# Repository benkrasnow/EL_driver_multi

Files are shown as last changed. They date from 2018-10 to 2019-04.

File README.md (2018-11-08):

# EL_driver_multi
Schematic, PCB, and firmware to build a multi-channel electroluminescent display driver

The MCU must be programmed with Adafruit's bootloader.  The programming pins are exposed on this PCB, but a potentially easier way is to buy a Trinket M0, and use a hotplate to remove the MCU, button, decoupling caps, LEDs current-limiting resistors and USB connector, and add those parts to this PCB.

The firmware for the driving of linear display elements (EL_array_linear) is pretty stable and well-commented.  The firmware for matrix driving (EL_array_matrix) is much more experimental.  It's accompanying Processing.org sketch is also a pretty hacked mod of Paul Stoffregen's original OctoWS2811 driver.

Driving EL matrix displays is not straightforward because scanning the matrix will undesirably illuminate pixels that are intended to be dark. This problem manifests as vertical bars in the image (when horizontal rows are scanned).  This could be improved with a tri-state high voltage shift register.

Video of my talk at Hackaday Supercon 2018, starting at the EL driver section:   https://youtu.be/Tx2B5hI4w1U?t=1473



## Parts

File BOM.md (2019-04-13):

Bill of Materials
---
|ID|Part Number|Description|Qty.|
|---|---|---|---|
|**HV Charge Circuit**|
|TR1, TR2|ATB3225|Step-Up Transformer|2|
|U2, U6|LT3468| Photoflash Charger|2|
|D1, D2|B0540W|0.5A SOD123 SCHOTTKY BARRIER RECTIFIER|2|
|D3, D4|MMBD5004S|HIGH VOLTAGE DUAL SWITCHING DIODE|2|
|C4|-|2.2μF 2220 (5750) SMD Capacitor|1|
|C5, C9|-|6.3μF 0603 SMD Capacitor|2|
|C6|-|100pF 0603 SMD Capacitor|1|
|R2|-|10MOhm 0603 SMD Resistor|1|
|R3|-|100kOhm 0603 SMD Resistor|1|
|**HV Control Circuit**|
|U1|HV513|8-Channel Low voltage serial to high voltage parallel IC|1|
| | |*OR*| |
|U9|HV507|64-Channel Low voltage serial to high voltage parallel IC|1|
|**LV Control Circuit**| |*All Components possibly from Tinket-M0*|
|U?|ATSAMD21E|Trinket M0 CPU|1|
|U3|AP2204K-3.3|3.3V Voltage regulator|1|
|U4|AP2204K-5.0|5.0V Voltage regulator|1|
|C2, C3|-|1μF 0603 SMD Capacitor|2|
|C1, C7, C8|-|10μF 0805 SMD Capacitor|3|
|R1|-|1.5kOhm 0603 SMD Resistor|1|
|R4|-|10kOhm 0603 SMD Resistor|1|
|L1|-|Red 0603 SMD LED|1|
|PWR1|-|Green Bright 0603 SMD LED|1|
|Q2|-|Tactile Switch SMT4.6X2.8|1|
|CN1|-|Micro USB Female|1|

Digikey Cart
---
*Parts excluding 0603 caps and resistors, and microcontroller stuff:*
- Double quantity except for HV507 https://www.digikey.com/short/pc8p74
- Single quantity https://www.digikey.com/short/pc8p89

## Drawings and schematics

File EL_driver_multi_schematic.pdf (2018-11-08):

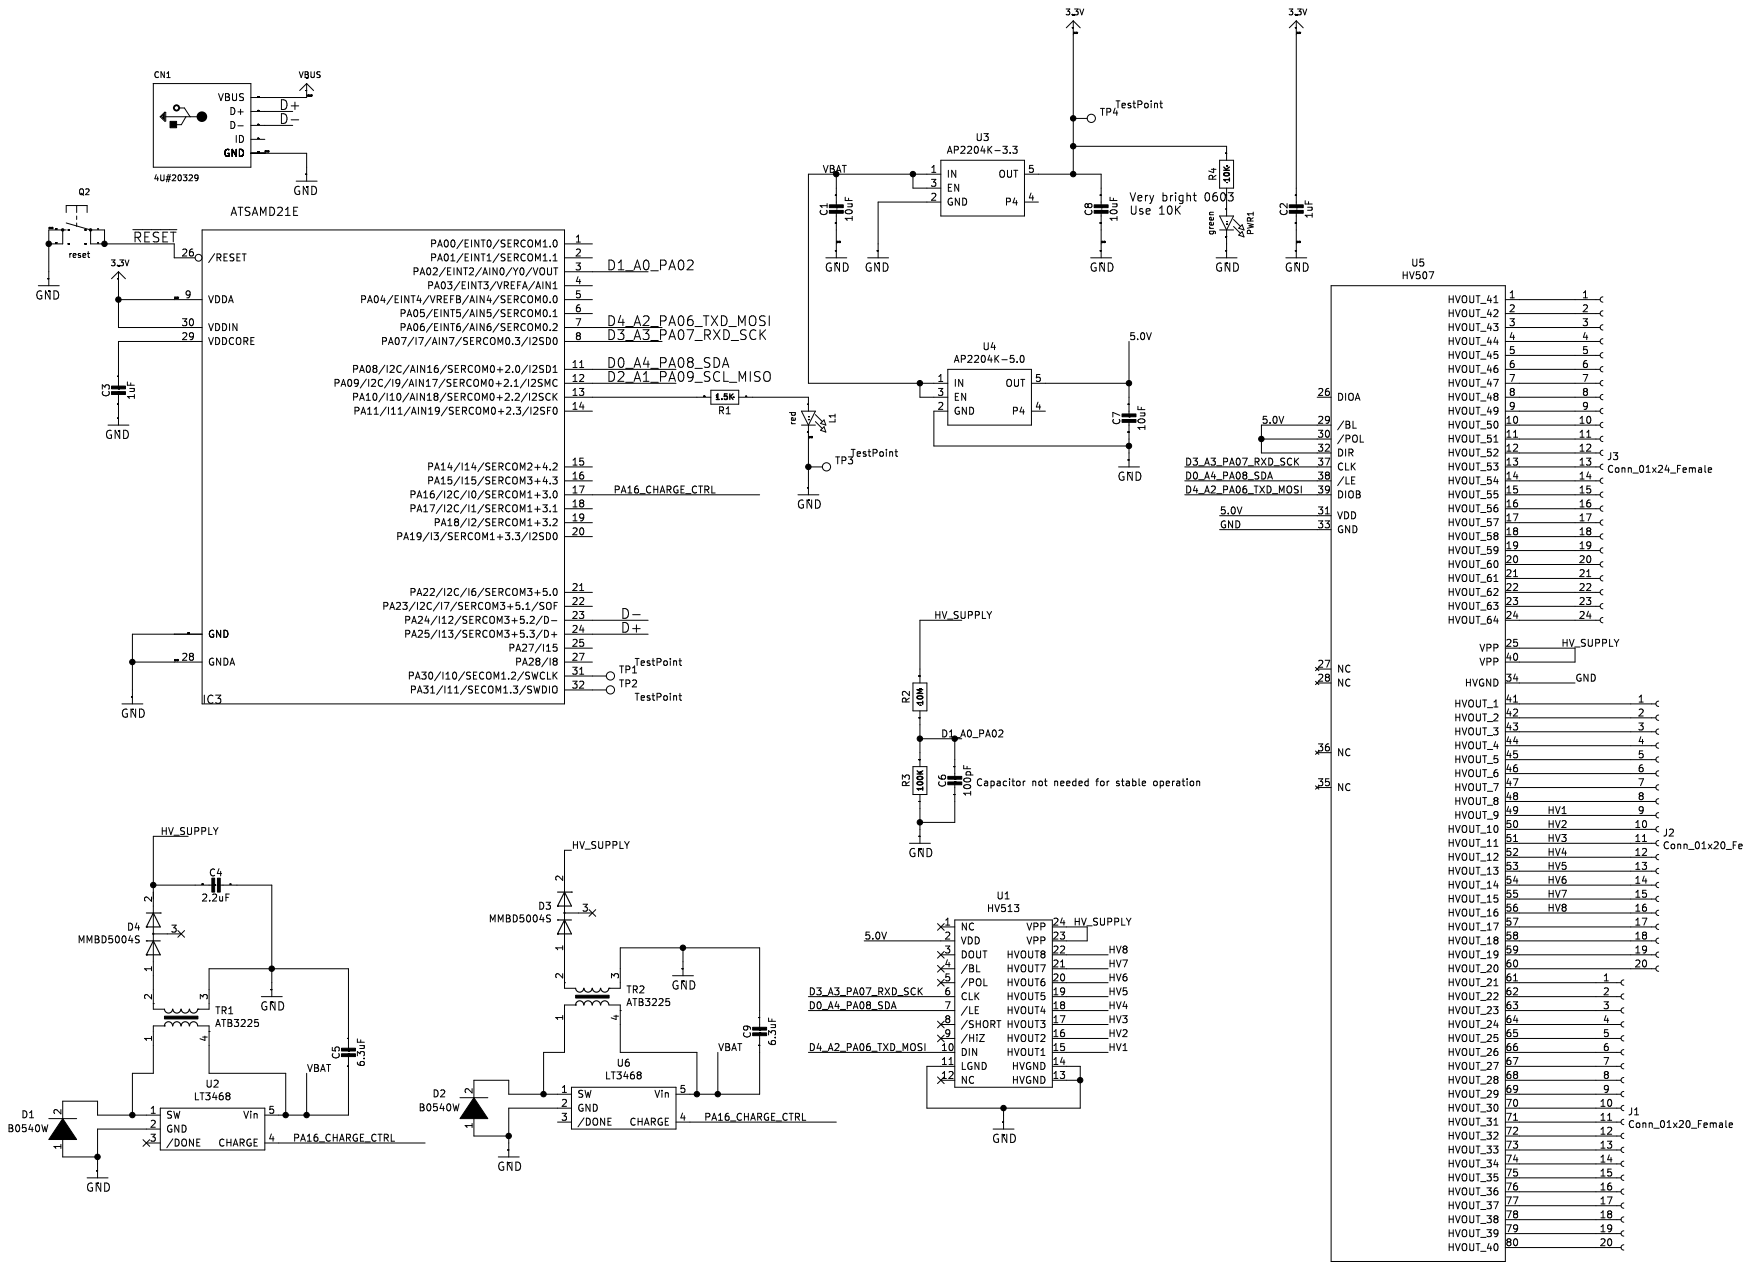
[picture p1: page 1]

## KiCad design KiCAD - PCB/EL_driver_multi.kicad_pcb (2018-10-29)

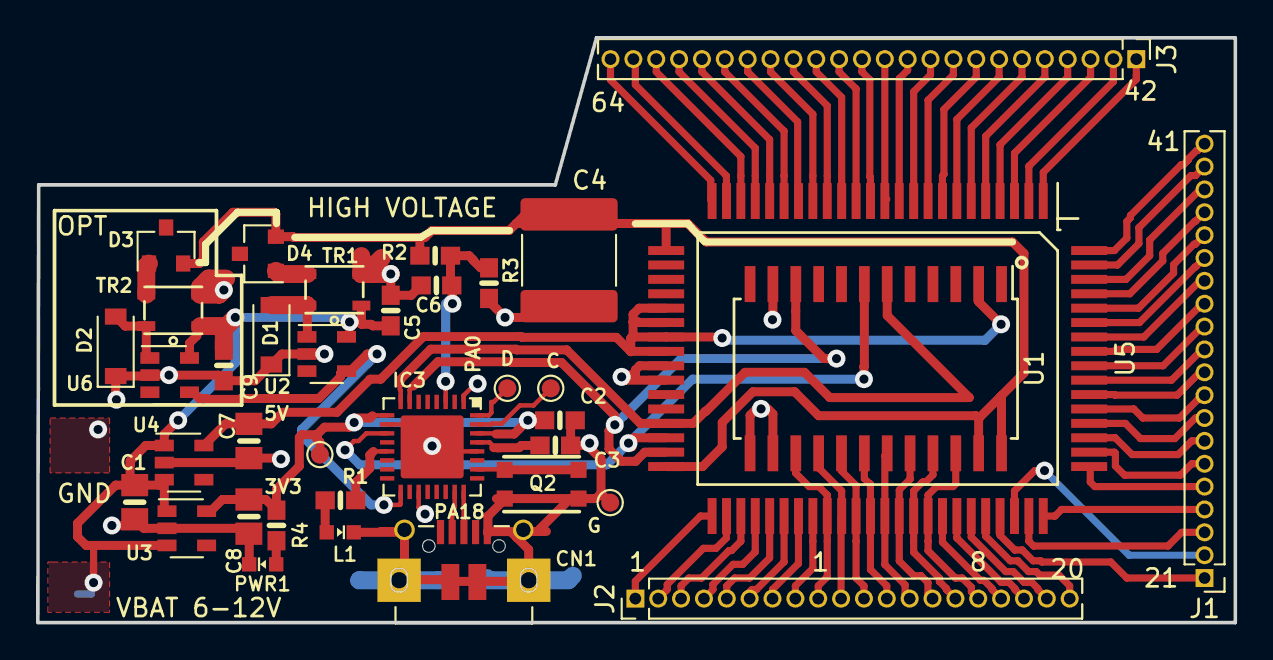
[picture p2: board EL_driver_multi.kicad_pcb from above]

Board: 2 copper layers, 66.5 x 32.5 mm, 37 parts (0 on the bottom side), 87 nets.

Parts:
C1, C7, C8: 10uF; 0805-NO
C2, C3: 1uF; 0603-NO
C4: 2.2uF; C_2220_5650Metric
C5, C9: 6.3uF; 0603-NO
C6: 0.1uF; 0603-NO
CN1: 4U#20329; 4UCONN_20329_V2
D1, D2: B0540W; D_SOD-123
D3, D4: MMBD5004S; SOT-23
IC3: ATSAMD21E; QFN32_5MM
J1, J2: Conn_01x20_Female; PinHeader_1x20_P1.27mm_Vertical
J3: Conn_01x24_Female; PinHeader_1x24_P1.27mm_Vertical
L1: red; CHIPLED_0603_NOOUTLINE
PWR1: green; CHIPLED_0603_NOOUTLINE
Q2: reset; BTN_KMR2_4.6X2.8
R1: 1.5K; 0603-NO
R2: 10M; 0603-NO
R3: 100K; 0603-NO
R4: 10K; 0603-NO
TP1, TP2, TP3, TP4: TestPoint; TestPoint_Pad_D1.0mm
TR1, TR2: ATB3225
U1: HV513; SOIC-24W_7.5x15.4mm_P1.27mm
U2, U6: LT3468; SOT-23-5
U3: AP2204K-3.3; SOT-23-5
U4: AP2204K-5.0; SOT-23-5
U5: HV507; QFP-96_14x20_Pitch0.8mm

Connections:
3.3V: C2.1, C8.1, IC3.9, IC3.30, R4.2, TP4.1, U3.5
/5.0V: C7.1, U1.2, U4.5, U5.29, U5.30, U5.31, U5.32
/D0_A4_PA08_SDA: IC3.11, U1.7, U5.38
/D1_A0_PA02: C6.1, IC3.3, R2.1, R3.2
/D3_A3_PA07_RXD_SCK: IC3.8, U1.6, U5.37
/D4_A2_PA06_TXD_MOSI: IC3.7, U1.10, U5.39
/D+: CN1.D+, IC3.24
/D-: CN1.D-, IC3.23
/HV1: J2.9, U1.15, U5.49
/HV2: J2.10, U1.16, U5.50
/HV3: J2.11, U1.17, U5.51
/HV4: J2.12, U1.18, U5.52
/HV5: J2.13, U1.19, U5.53
/HV6: J2.14, U1.20, U5.54
/HV7: J2.15, U1.21, U5.55
/HV8: J2.16, U1.22, U5.56
/HV_SUPPLY: C4.2, D3.2, D4.2, R2.2, U1.23, U1.24, U5.25, U5.40
/PA16_CHARGE_CTRL: IC3.17, U2.4, U6.4
/VBAT: C1.1, C5.2, C9.2, TR1.4, TR2.4, U2.5, U3.1, U3.3, U4.1, U4.3, U6.5
/~RESET: IC3.26, Q2.A, Q2.A'
GND: C1.2, C2.2, C3.2, C4.1, C5.1, C6.2, C7.2, C8.2, C9.1, CN1.BASE@1, CN1.BASE@2, CN1.GND, CN1.SPRT@1, CN1.SPRT@2, CN1.SPRT@3, CN1.SPRT@4, D1.1, D2.1, IC3.10, IC3.28, IC3.33, L1.C, PWR1.C, Q2.B, Q2.B', R3.1, TP3.1, TR1.3, TR2.3, U1.11, U1.13, U1.14, U2.2, U3.2, U4.2, U5.33, U5.34, U6.2
unnamed: C3.1, IC3.29
unnamed: D1.2, TR1.1, U2.1
unnamed: D2.2, TR2.1, U6.1
unnamed: D3.1, TR2.2
unnamed: D4.1, TR1.2
unnamed: IC3.13, R1.2
unnamed: IC3.31, TP1.1
unnamed: IC3.32, TP2.1
unnamed: J1.1, U5.61
unnamed: J1.2, U5.62
unnamed: J1.3, U5.63
unnamed: J1.4, U5.64
unnamed: J1.5, U5.65
unnamed: J1.6, U5.66
unnamed: J1.7, U5.67
unnamed: J1.8, U5.68
unnamed: J1.9, U5.69
unnamed: J1.10, U5.70
unnamed: J1.11, U5.71
unnamed: J1.12, U5.72
unnamed: J1.13, U5.73
unnamed: J1.14, U5.74
unnamed: J1.15, U5.75
unnamed: J1.16, U5.76
unnamed: J1.17, U5.77
unnamed: J1.18, U5.78
unnamed: J1.19, U5.79
unnamed: J1.20, U5.80
unnamed: J2.1, U5.41
unnamed: J2.2, U5.42
unnamed: J2.3, U5.43
unnamed: J2.4, U5.44
unnamed: J2.5, U5.45
unnamed: J2.6, U5.46
unnamed: J2.7, U5.47
unnamed: J2.8, U5.48
unnamed: J2.17, U5.57
unnamed: J2.18, U5.58
unnamed: J2.19, U5.59
unnamed: J2.20, U5.60
unnamed: J3.1, U5.1
unnamed: J3.2, U5.2
unnamed: J3.3, U5.3
unnamed: J3.4, U5.4
unnamed: J3.5, U5.5
unnamed: J3.6, U5.6
unnamed: J3.7, U5.7
unnamed: J3.8, U5.8
unnamed: J3.9, U5.9
unnamed: J3.10, U5.10
unnamed: J3.11, U5.11
unnamed: J3.12, U5.12
unnamed: J3.13, U5.13
unnamed: J3.14, U5.14
unnamed: J3.15, U5.15
unnamed: J3.16, U5.16
unnamed: J3.17, U5.17
unnamed: J3.18, U5.18
unnamed: J3.19, U5.19
unnamed: J3.20, U5.20
unnamed: J3.21, U5.21
unnamed: J3.22, U5.22
unnamed: J3.23, U5.23
unnamed: J3.24, U5.24
unnamed: L1.A, R1.1
unnamed: PWR1.A, R4.1

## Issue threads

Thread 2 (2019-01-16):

Serial port not initialized

artelse, 2019-01-16:
Trying out the Arduino matrix code on a Trinket M0. It compiles fine, code uploads, but then get an error that the serial port (/dev/ttyACM0) isn't initialized. Any hints?
Edit: I did see your comment:
`//Don't forget that this MCU is also running a USB ISR if loaded normally through the Arduino IDE as an Adafruit Trinket M0.  This uses some CPU time, but also allows serial communication for new features or debugging.`
So serial should work?
I noticed the omission of mandatory `Serial.begin(baudrate);`. But, adding it doesn't fix the problem.

benkrasnow, 2019-04-13:
Sorry for the delay.  Did you get it working?  Can you run any Trinket M0 examples?  On my Windows computer, I have to select a different COM port for debugging than for programming (it re-initializes when the Trinket boots and establishes a new COM port)

artelse, 2019-04-22:
Hi, thanks for the feedback. I am able now to upload a simple serial port program and this works (see code below if someone wants to test).
Next step is to get the matrix code tested. Will report back on my results.
```
// UF2 Bootloader v1.23.0 SFHR
// Model: Trinket M0
// Board-ID: SAMD21E18A-Trinket-v0

// the setup function runs once when you press reset or power the board
void setup() {
  // initialize digital pin 13 as an output.
  pinMode(13, OUTPUT);
  Serial.begin(9600);
}
// the loop function runs over and over again forever
void loop() {
  Serial.println("hello");
  digitalWrite(13, HIGH);   // turn the LED on (HIGH is the voltage level)
  delay(1000);              // wait for a second
  digitalWrite(13, LOW);    // turn the LED off by making the voltage LOW
  delay(1000);              // wait for a second
}
```

artelse, 2019-05-03:
Haven't found a fix yet, but when I disable `NVIC_EnableIRQ(TCC2_IRQn);`, the serial port works. I also swapped with the next line to `NVIC_SetPriority(TCC2_IRQn, 0);' because it makes sense to set priority first.
The problem you have with the serial port on Windows is described [here](https://www.avdweb.nl/arduino/samd21/virus). None of these fixes my problem though, so it must have to do something with the timer interrupt?
Can you point me to documentation of register settings, library, etc. as this processor is new to me and want to dig into it more. Thx!

artelse, 2019-05-16:
Ok, couldn't find why enabling that interrupt locked up the cpu. So loaded the code on a fresh Trinket M0 original board and now it runs just fine. My idea now is that I have damaged the ADC input somehow because I had an issue with the 100:1 voltage divider.

Closed 2019-05-16.

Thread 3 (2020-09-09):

Inverter Design Question + Hello

tyVandeZande, 2020-09-09:
Hi, first, this is so so awesome. Thank you!

Second I have been working with EL screen printing and airbrushing for a few years– I've run into and troubleshooted most every possible problem with the materials! If anyone has questions about issues with application process or bizarre defects ((there can be many weird issues with EL)) — Feel free to reach out!

Third Inverter Design– I have no engineering background and am self teaching electronics from your videos + others on youtube. So please forgive me if I am missing some trivial//obvious electronics knowledge.

Does Pin 3 on the transformer need to be tied to GND? It seems safer for a person if the HV is isolated, rather than connected to GND. It looks like in the current design, if someone accidentally touches The EL and some other piece of the circuit (including batteries or a computer this is plugged into), the circuit would short through the user. Am I mistaking?

Also, what is the purpose of D3/D4 MMBD004S ?

Thank you so much for your time and contributions!

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

benkrasnow, 2020-09-10:
In my original application, the EL segments were controlled by a switching IC, which requires a high voltage DC rail (up to 300V), and this rail must be referenced to GND, the same GND as the logic control of the IC.  This is why pin 3 of the transformer ATB3225 is grounded.  The diode MMBD5004 rectifies the AC into a pulsating DC, which is smoothed by a capacitor that was shown on my original schematic.  Two diodes are in series so that their rated blocking voltages are summed together.  Diode B0540 prevents pin 1 of LT3468 from undershooting GND due to inductive kick from the switchmode control of the transformer.

If you want to run a single EL panel directly from the transformer without the switching IC, you can probably connect it directly to the transformer and not ground pin 3.

tyVandeZande, 2020-09-10:
Okay, gotcha Re: Pin3. If the HVGND is never referenced to GND, it could cause errors in the gates in the switching IC because the logic gates are "riding" and variable voltage? I believe I've heard someone call that a ground loop interference before?

In my previous controller designs, I've been using an array of triacs to control each segment–using the triacs basically as a relay (schematic attached) This design has two separate power sources, one for inverter and one for the logic. In my schematic, if there is an unstable connection between an EL segment and the triac, my Teensy freaks, spits gibberish over Serial, then restarts ((Teensy hasn't bricked yet)) – But if theres a stable connection, the program runs fine for a while! Hah.

Diodes: That totally makes sense, thanks again!
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

Closed 2020-09-10.

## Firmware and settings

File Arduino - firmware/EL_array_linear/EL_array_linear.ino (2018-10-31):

#include <SPI.h>

#define PIN_SPI_DAT 4  //Using hardware SPI.  Pins are defined here just for completeness
#define PIN_SPI_CLK 3
#define PIN_SPI_LE 0  //Latch enable on both the HV513 nad HV507

#define PIN_HV_CTRL PA16  // This constant is not used in the code, PA16 is accessed via registers directly



#define MAX_BRIGHTNESS 128  // The shift register is refreshed at 8.5KHz (somewhat arbitrary choice).  In order to avoid flicker, the "frame rate" should be >75Hz.
                            // The frame rate will be shift register refresh divided by MAX_BRIGHTNESS 8500/63 = 134Hz
                            // This constant can be set to other values (doesn't have to be a power of two), and the code will adjust the framerate inherently.



//Uncomment only one of these lines to indicate which high-voltage chip is being used
//#define USE_HV513
#define USE_HV507


#define HV_ADC_SETPOINT 600   // ADC value to which the high voltage will be regulated.  ADC is set to 10 bits, reference is 3.3V, and HV divider is 100, so divide this value by 3.1 (2^10/(3.3*100)) to get voltage.  600/3.1 = 193V
                               // BE CAREFUL! Setting this value too high can destroy hardware!   The HV513 has an absolute maximum of 275V, and there will be some overshoot/spikes above the set voltage.





#ifdef USE_HV513
#define NUM_PIXELS 4  //8-bit shift register, 4 pairs
#define SR_BYTES 1
#endif

#ifdef USE_HV507
#define NUM_PIXELS 32  //64-bit shift register, 32 pairs
#define SR_BYTES 8
#endif

SPISettings SPI_HV513(6000000, MSBFIRST, SPI_MODE0);  //8MHz limit for HV513
SPISettings SPI_HV507(8000000, MSBFIRST, SPI_MODE0);  //8MHz limit for HV7224

#define SR_TOGGLE_MASK 0x00000003  // Binary 11.  We'll shift this pair of 1's along the length of the shift register to control each output pair



//Global variables
int pixelvalues[NUM_PIXELS];  //Range is 0 (off) to MAX_BRIGHTNESS.  Originally, I used a floating point value (0 to 1.0), but this was too slow to process in the ISR.
byte srvalue[SR_BYTES];
int fade_step;


void setup() 
{ 
  //Clock distribution to the counters
  
  REG_GCLK_CLKCTRL = GCLK_CLKCTRL_CLKEN |         // Enable GCLK0 to TCC0 and TCC1
                     GCLK_CLKCTRL_GEN_GCLK0 |     // Select GCLK0
                     GCLK_CLKCTRL_ID_TCC0_TCC1 ;  // Feed GCLK0  TCC0, and TCC1
  while (GCLK->STATUS.bit.SYNCBUSY);              // Wait for synchronization


  REG_GCLK_CLKCTRL = GCLK_CLKCTRL_CLKEN |         // Enable GCLK0 to TCC2 and TC3
                     GCLK_CLKCTRL_GEN_GCLK0 |     // Select GCLK0
                     GCLK_CLKCTRL_ID_TCC2_TC3 ;   // Feed GCLK0  TCC2, and TC3
  while (GCLK->STATUS.bit.SYNCBUSY);              // Wait for synchronization





 //  The following counter will trigger an interrupt that initiates a SPI transaction with the shift register
 //  In an alternative system, the frequency output was used external of the MCU, but it's not needed any longer, so the port setup is commented out.
 //  DMA could have been used, but we're only sending either one or 8 bytes at 8.5KHz, so the DMA overhead may cancel any benefit for such a small transaction. Most of the time is spent in computation, not SPI transmission
 //  PORT->Group[0].PINCFG[8].reg |= PORT_PINCFG_PMUXEN;
 //  PORT->Group[0].PMUX[8 >> 1].reg = PORT_PMUX_PMUXE_F;
  
  REG_TCC1_WAVE |=  TCC_WAVE_WAVEGEN_NPWM;    // Setup simple PWM
  while (TCC1->SYNCBUSY.bit.WAVE);               // Wait for synchronization

  // Each timer counts up to a value set by the PER register
  REG_TCC1_PER = 1400;         // Set the frequency of the interrupt on TCC1  12MHz / 1200 = 10KHz ;  12MHz / 1400 = 8.57KHz
  while (TCC1->SYNCBUSY.bit.PER);                // Wait for synchronization
  
  REG_TCC1_CC0 = 1400;         // TCC0 CC0
  while (TCC1->SYNCBUSY.bit.CC0);                // Wait for synchronization

  //Enable an interrupt on a counter (CNT) event
  REG_TCC1_INTENSET |= TCC_INTENSET_CNT;

  //Specify the interrupting counter event to be an END event
  //This could have been done with an overflow interrupt event as well, but this arangement was left over from an alterative control system, and there is nothing wrong with using a CNT event
  REG_TCC1_EVCTRL |= TCC_EVCTRL_CNTSEL_END;

  NVIC_EnableIRQ(TCC1_IRQn);
   
  
  REG_TCC1_CTRLA |= TCC_CTRLA_PRESCALER_DIV4 |    // Divide GCLK4 by 4 48MHz/4 = 12MHz
                    TCC_CTRLA_ENABLE;             // Enable the TCC0 output
  while (TCC1->SYNCBUSY.bit.ENABLE);              // Wait for synchronization





  //Setup PWM output for control of high voltage supply
  
  PORT->Group[0].PINCFG[16].reg |= PORT_PINCFG_PMUXEN;    //Enable pin multiplexer
  PORT->Group[0].PINCFG[16].reg |= PORT_PINCFG_PULLEN;    //Enable pull-down resistor on this pin.  In timer one-shot mode, the pin appears to go high-Z after the timer ends, but cannot find this in the documentation
  PORT->Group[0].PMUX[16 >> 1].reg = PORT_PMUX_PMUXO_E | PORT_PMUX_PMUXE_E;   // PA16 is an even-numbered pin, so PMUXE_E  means set this even numbered pin to port function "E", which is TCC2
  
  REG_TCC2_WAVE |=  TCC_WAVE_WAVEGEN_NPWM  | TCC_WAVE_POL(0xF) ;    // Setup normal PWM and invert polarity on all 4 CC channels
  while (TCC2->SYNCBUSY.bit.WAVE);                                  // "invert" means the output is normally low.  The counter starts at 0, and counts up, turning on the ouput when it matches CCx
  
  REG_TCC2_PER = 2000;         // Period:  set the frequency of the PWM on TCC2  3MHz/2000 = 1.5KHz
  while (TCC2->SYNCBUSY.bit.PER);               
  
  REG_TCC2_CC0 = 2001;         // CC is initially set *above* PER, which means the output will never go high
  while (TCC2->SYNCBUSY.bit.CC0);    


  //The counter is configured as a one-shot, and PA16 goes low when CC0 is reached or the cycle ends.  The pin actually appears to go Hi-Z when the cycle ends -- not sure.
  //This was done so that if the MCU halts for some unforeseen reason, the high voltage supply is shut down by default (fail safe).
  //This arrangement requires the ISR to run periodically in order for high voltage to be generated
  REG_TCC2_CTRLBSET = TCC_CTRLBSET_ONESHOT;
  while (TCC2->SYNCBUSY.bit.CTRLB);

  //Enable an interrupt on an overflow (the counter reaches PER)
  TCC2->INTENSET.reg = TCC_INTENSET_OVF;
  
  NVIC_EnableIRQ(TCC2_IRQn);
  NVIC_SetPriority(TCC2_IRQn, 0);
  
  REG_TCC2_CTRLA |= TCC_CTRLA_PRESCALER_DIV16 |    // Divide GCLK4 by 16  48MHz/16 = 3MHz
                    TCC_CTRLA_ENABLE;             // Enable the TCC2 output
  while (TCC2->SYNCBUSY.bit.ENABLE);              // Wait for synchronization





  //The default ADC setup for the M0 in Arduino is super slow -- over one millisecond per conversion, so we need to speed it up! 
  ADC->CTRLB.reg = ADC_CTRLB_PRESCALER_DIV32 |    // Divide Clock ADC GCLK by 32 (48MHz/32 = 1.5MHz)   Maximum allowed speed is about 2.1 MHz
                 ADC_CTRLB_RESSEL_10BIT;         // Set ADC resolution to 10 bits
  while(ADC->STATUS.bit.SYNCBUSY);                 // Wait for synchronization
  ADC->SAMPCTRL.reg = 0x00;                        // Set max Sampling Time Length to half divided ADC clock pulse




  pinMode(PIN_SPI_LE, OUTPUT);
  digitalWrite(PIN_SPI_LE, HIGH);

//Initialize the shift register array
  for(int i = 0; i < SR_BYTES; i++)
    {
      srvalue[i] = 170;   // This value is used because it is an 8-bit number with alternating 1's and 0's in binary.  Each sequential pair of pins in the shift register controls an EL segment, for which we want a voltage applied, and thus need alternating 1 and 0.
    }
  
  SPI.begin();

  
}






void loop() {
int i;
float t = 0.0;
unsigned int lastTime = 0;



for(i=0;i<500;i++)
{
//pixelvalues[0] = 63;
pixelvalues[0] = (int)((sin(t)+1.0)*0.5*MAX_BRIGHTNESS);
pixelvalues[1] = (int)((sin(t+0.785)+1.0)*0.5*MAX_BRIGHTNESS);
//pixelvalues[2] = (sin(t+1.57)+1.0)*0.5;
//pixelvalues[3] = (sin(t+2.355)+1.0)*0.5;

t = t + 0.05;

if (t > 6.28)
  {
    t = 0.0;
  }
delay(10);
}


/*


for(i=0;i<400;i++)
  {
    for(int z = 0 ; z < NUM_PIXELS ; z++)
      {
        pixelvalues[z] = 1.0;
      }
    
    delay(10);
  }
*/



/*

for(i=0;i<24;i++)
  {
    pixelvalues[0] = (i%2) ? 0 : 127;
    pixelvalues[1] = 0;
    pixelvalues[2] = 0;
    pixelvalues[3] = 0;
    delay(100);
  }

for(i=0;i<18;i++)
  {
    pixelvalues[0] = (i%2) ? 0 : 127;
    pixelvalues[1] = (i%2) ? 0 : 127;
    pixelvalues[2] = 0;
    pixelvalues[3] = 0;
    delay(100);
  }

  for(i=0;i<12;i++)
  {
    pixelvalues[0] = (i%2) ? 0 : 127;
    pixelvalues[1] = (i%2) ? 0 : 127;
    pixelvalues[2] = (i%2) ? 0 : 127;
    pixelvalues[3] = 0;
    delay(100);
  }

 for(i=0;i<6;i++)
  {
    pixelvalues[0] = (i%2) ? 0 : 127;
    pixelvalues[1] = (i%2) ? 0 : 127;
    pixelvalues[2] = (i%2) ? 0 : 127;
    pixelvalues[3] = (i%2) ? 0 : 127;
    delay(100);
  }
*/

}




//Don't forget that this MCU is also running a USB ISR if loaded normally through the Arduino IDE as an Adafruit Trinket M0.  This uses some CPU time, but also allows serial communication for new features or debugging.


//  This ISR will send data to the shift register.  Duration measured at under 20us for the HV513, runs at 8.5KHz, so 17% of CPU time.  Shifting the additional bytes for the HV507 brings the total time up to 40us
//  The code in here has to be very efficient.  I originally used a floating point array to store the pixel brightness values, and did floating point math in the ISR, but this was way too slow.
void TCC1_Handler() 
{
  //  __disable_irq();
  int i;
  for(i =0; i< NUM_PIXELS; i++)
    {
      if (fade_step < pixelvalues[i])
        {                       //I use srvalue[i>>2] because there are four pair of EL outputs per byte of shift register so we divide pixels (ie pairs) by four, which is the same as right-shift 2
          srvalue[(i>>2)] ^= (SR_TOGGLE_MASK << ((i%4)<<1));  //The exclusive OR will toggle the pair of pins, giving a flash of light from the EL.  i<<1 because we are moving through the register by pairs.
        }
     }

  fade_step = ++fade_step > MAX_BRIGHTNESS ? 0 : fade_step;

 #ifdef USE_HV513
  digitalWriteDirect(PIN_SPI_LE, LOW);  //Latch enable is brought low while shifting in new data
  SPI.beginTransaction(SPI_HV513);
  SPI.transfer(srvalue[0]);
  SPI.endTransaction();
  digitalWriteDirect(PIN_SPI_LE, HIGH);
 #endif


 #ifdef USE_HV507
  digitalWriteDirect(PIN_SPI_LE, LOW);  //Latch enable is brought low while shifting in new data
  SPI.beginTransaction(SPI_HV507);
  SPI.transfer(srvalue[7]);
  SPI.transfer(srvalue[6]);
  SPI.transfer(srvalue[5]);
  SPI.transfer(srvalue[4]);
  SPI.transfer(srvalue[3]);
  SPI.transfer(srvalue[2]);
  SPI.transfer(srvalue[1]);
  SPI.transfer(srvalue[0]);
  SPI.endTransaction();
  digitalWriteDirect(PIN_SPI_LE, HIGH);
 #endif
  
 REG_TCC1_INTFLAG |= TCC_INTFLAG_CNT;
 NVIC_ClearPendingIRQ(TCC1_IRQn);
 //  __enable_irq();
 
}




//  Voltage regulation interrupt handler.  Duration measured at 15us, runs at 1.5KHz, so about 2% of all CPU time
void TCC2_Handler() 
{ 
  __disable_irq();
   NVIC_ClearPendingIRQ(TCC2_IRQn);
  TCC2->INTFLAG.reg = TCC_INTFLAG_OVF;
  
  if(analogRead(A0) < HV_ADC_SETPOINT)  //Voltage is below setpoint, so set CC0 to a low value to make the output go high near the beginning of the timing cycle.
    {
      REG_TCC2_CC0 = 40;        // This must not be set to 0 or "too low" a value.  The LT3468 datasheet specs a minimum low time of 20us. The counter is 3MHz, so this delay of "40" is 13us, plus the ISR latency.   
      while (TCC2->SYNCBUSY.bit.CC0);   //I've destroyed an LT3468 by cycling the control line too rapidly.  Also, it might work to keep this line high continuously, but it's not easy to do that with this MCU timer config, and
    }                                   // sometimes the LT3468 decides it's done charging and ignores the input, so the control line must be cycled often to have decent voltage control.
  else
    {
      REG_TCC2_CC0 = 2001;        // Voltage is above setpoint, so set CC0 above PER, causing the output to always be low
      while (TCC2->SYNCBUSY.bit.CC0); 
    }
  
  TCC2->CTRLBSET.reg = TCC_CTRLBSET_CMD_RETRIGGER;
  
  __enable_irq();
}




inline void digitalWriteDirect(int PIN, boolean val)
{
  if(val)  PORT->Group[g_APinDescription[PIN].ulPort].OUTSET.reg = (1ul << g_APinDescription[PIN].ulPin);
  else     PORT->Group[g_APinDescription[PIN].ulPort].OUTCLR.reg = (1ul << g_APinDescription[PIN].ulPin);
}










  /*
  REG_GCLK_GENDIV = GCLK_GENDIV_DIV(1) |          // Divide the 48MHz clock source by divisor 1: 48MHz/1=48MHz
                    GCLK_GENDIV_ID(4);            // Select Generic Clock (GCLK) 4
  while (GCLK->STATUS.bit.SYNCBUSY);              // Wait for synchronization

  REG_GCLK_GENCTRL = GCLK_GENCTRL_IDC |           // Set the duty cycle to 50/50 HIGH/LOW
                     GCLK_GENCTRL_GENEN |         // Enable GCLK4
                     GCLK_GENCTRL_SRC_DFLL48M |   // Set the 48MHz clock source
                     GCLK_GENCTRL_ID(4);          // Select GCLK4
  while (GCLK->STATUS.bit.SYNCBUSY);              // Wait for synchronization
*/

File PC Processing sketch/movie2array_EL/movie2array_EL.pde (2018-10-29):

/*  OctoWS2811 movie2serial.pde - Transmit video data to 1 or more
      Teensy 3.0 boards running OctoWS2811 VideoDisplay.ino
    http://www.pjrc.com/teensy/td_libs_OctoWS2811.html
    Copyright (c) 2018 Paul Stoffregen, PJRC.COM, LLC
    Permission is hereby granted, free of charge, to any person obtaining a copy
    of this software and associated documentation files (the "Software"), to deal
    in the Software without restriction, including without limitation the rights
    to use, copy, modify, merge, publish, distribute, sublicense, and/or sell
    copies of the Software, and to permit persons to whom the Software is
    furnished to do so, subject to the following conditions:
    The above copyright notice and this permission notice shall be included in
    all copies or substantial portions of the Software.
    THE SOFTWARE IS PROVIDED "AS IS", WITHOUT WARRANTY OF ANY KIND, EXPRESS OR
    IMPLIED, INCLUDING BUT NOT LIMITED TO THE WARRANTIES OF MERCHANTABILITY,
    FITNESS FOR A PARTICULAR PURPOSE AND NONINFRINGEMENT. IN NO EVENT SHALL THE
    AUTHORS OR COPYRIGHT HOLDERS BE LIABLE FOR ANY CLAIM, DAMAGES OR OTHER
    LIABILITY, WHETHER IN AN ACTION OF CONTRACT, TORT OR OTHERWISE, ARISING FROM,
    OUT OF OR IN CONNECTION WITH THE SOFTWARE OR THE USE OR OTHER DEALINGS IN
    THE SOFTWARE.
*/

// Linux systems (including Raspberry Pi) require 49-teensy.rules in
// /etc/udev/rules.d/, and gstreamer compatible with Processing's
// video library.

// To configure this program, edit the following sections:
//
//  1: change myMovie to open a video file of your choice    ;-)
//
//  2: edit the serialConfigure() lines in setup() for your
//     serial device names (Mac, Linux) or COM ports (Windows)
//
//  3: if your LED strips have unusual color configuration,
//     edit colorWiring().  Nearly all strips have GRB wiring,
//     so normally you can leave this as-is.
//
//  4: if playing 50 or 60 Hz progressive video (or faster),
//     edit framerate in movieEvent().

import processing.video.*;
import processing.serial.*;
import java.awt.Rectangle;

Movie myMovie;

float gamma = 1.7;

int numPorts=0;  // the number of serial ports in use
int maxPorts=24; // maximum number of serial ports

Serial[] ledSerial = new Serial[maxPorts];     // each port's actual Serial port
Rectangle[] ledArea = new Rectangle[maxPorts]; // the area of the movie each port gets, in % (0-100)
boolean[] ledLayout = new boolean[maxPorts];   // layout of rows, true = even is left->right
PImage[] ledImage = new PImage[maxPorts];      // image sent to each port
int[] gammatable = new int[256];
int errorCount=0;
float framerate=0;

void settings() {
  size(800, 800);  // create the window
}

void setup() {
  String[] list = Serial.list();
  delay(20);
  println("Serial Ports List:");
  println(list);
 
 
 
 // serialConfigure("/dev/ttyACM0");  // change these to your port names
//  serialConfigure("/dev/ttyACM1");
  ledImage[0] = new PImage(32, 32, RGB);
  ledArea[0] = new Rectangle(20, 0, 60, 100);
  ledLayout[0] = true;
  numPorts = 1;
  ledSerial[0] = new Serial(this, "COM14");
  
  

  if (errorCount > 0) exit();
  for (int i=0; i < 256; i++) {
    gammatable[i] = (int)(pow((float)i / 255.0, gamma) * 255.0 + 0.5);
  }
  myMovie = new Movie(this, "vertical.avi");   //Put the video files in the ./data directory
  myMovie.loop();  // start the movie :-)
}


// movieEvent runs for each new frame of movie data
void movieEvent(Movie m) {
  println("movieEvent");
  // read the movie's next frame
  m.read();

  //if (framerate == 0) framerate = m.getSourceFrameRate();
  framerate = 30.0; // TODO, how to read the frame rate???

  for (int i=0; i < numPorts; i++) {
    // copy a portion of the movie's image to the LED image
    int xoffset = percentage(m.width, ledArea[i].x);
    int yoffset = percentage(m.height, ledArea[i].y);
    int xwidth =  percentage(m.width, ledArea[i].width);
    int yheight = percentage(m.height, ledArea[i].height);
    ledImage[i].copy(m, xoffset, yoffset, xwidth, yheight,
                     0, 0, ledImage[i].width, ledImage[i].height);
    
    // convert the LED image to raw data
    byte[] ledData =  new byte[(ledImage[i].width * ledImage[i].height * 3) + 3];
    image2databw(ledImage[i], ledData);
    
    
    if (i == 0) {
   //   ledData[0] = '*';  // first Teensy is the frame sync master
    //  int usec = (int)((1000000.0 / framerate) * 0.75);
    //  ledData[1] = (byte)(usec);   // request the frame sync pulse
    //  ledData[2] = (byte)(usec >> 8); // at 75% of the frame time
    ledData[0] = 0;
    ledData[1] = 0;
    ledData[2] = 0;
    
    } else {
      ledData[0] = '%';  // others sync to the master board
      ledData[1] = 0;
      ledData[2] = 0;
    }
    
    for(int g = 0; g < 20; g++)
      {
         println(int(ledData[g] & 0xFF));
      }
      
    // send the raw data to the LEDs  :-)
    ledSerial[i].write(ledData);
  }
}



void image2databw(PImage image, byte[] data) {
  int offset = 3;
  int x, y;

 // image.filter(GRAY);

  for(y = 0; y < image.height; y++)  {
     for( x= 0; x < image.width; x++) {
       image.pixels[x+ (y * image.width)] = color((image.pixels[x+ (y * image.width)]&0xE0));
       data[offset++] = byte( image.pixels[x+ (y * image.width)] +1  & 0x0000FF);
     }
  }
  
}


// image2data converts an image to OctoWS2811's raw data format.
// The number of vertical pixels in the image must be a multiple
// of 8.  The data array must be the proper size for the image.
void image2data(PImage image, byte[] data, boolean layout) {
  int offset = 3;
  int x, y, xbegin, xend, xinc, mask;
  int linesPerPin = image.height / 8;
  int pixel[] = new int[8];

  for (y = 0; y < linesPerPin; y++) {
    if ((y & 1) == (layout ? 0 : 1)) {
      // even numbered rows are left to right
      xbegin = 0;
      xend = image.width;
      xinc = 1;
    } else {
      // odd numbered rows are right to left
      xbegin = image.width - 1;
      xend = -1;
      xinc = -1;
    }
    for (x = xbegin; x != xend; x += xinc) {
      for (int i=0; i < 8; i++) {
        // fetch 8 pixels from the image, 1 for each pin
        pixel[i] = image.pixels[x + (y + linesPerPin * i) * image.width];
        pixel[i] = colorWiring(pixel[i]);
      }
      // convert 8 pixels to 24 bytes
      for (mask = 0x800000; mask != 0; mask >>= 1) {
        byte b = 0;
        for (int i=0; i < 8; i++) {
          if ((pixel[i] & mask) != 0) b |= (1 << i);
        }
        data[offset++] = b;
      }
    }
  }
}






// translate the 24 bit color from RGB to the actual
// order used by the LED wiring.  GRB is the most common.
int colorWiring(int c) {
  int red = (c & 0xFF0000) >> 16;
  int green = (c & 0x00FF00) >> 8;
  int blue = (c & 0x0000FF);
  red = gammatable[red];
  green = gammatable[green];
  blue = gammatable[blue];
  return (green << 16) | (red << 8) | (blue); // GRB - most common wiring
}
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

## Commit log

2018-10-29 Added PCB files
    [EL_driver_multi.kicad_pcb, EL_driver_multi.sch]
2018-10-31 Missing modulo operator in SR loading
    [EL_array_linear.ino]
2018-11-08 Added schematic PDF
2019-04-13 Added Bill of Materials (#1)
    * Created BOM manually
    * Update BOM.md
    * Fixed typos
    * Update BOM.md
    * Update BOM.md
    * Update BOM.md
